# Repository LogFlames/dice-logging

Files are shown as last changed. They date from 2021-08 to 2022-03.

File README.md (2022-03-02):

# Dice logging

This is the repo containing my project during the 2021 math camp.

The project is built using an ESP8266 and accelerometer (ADXL345).

To upload the code use the ESP8266 package for the arduino IDE. 

Add this to `File > Preferences > Additional Board Manager URLs` (http://arduino.esp8266.com/stable/package_esp8266com_index.json]. Goto `Tools > Board > Board Manager` and install the ESP8266 module. Select `Generic ESP8266 Module` in `Tools > Board`.

Goto `Sketch > Include Library > Manage Libraries` and install the NTPClient. Install the Adafruit ADXL_345 library aswell.

The ClockifyAPI documentation can be found at: (https://clockify.me/developers-api)[!https://clockify.me/developers-api]

## Model
The model can be built using openSCAD. It was sliced with the PrusaSlicer at 0.15mm layer height.

If you wish to only have one model, change the following code in 'dice_cad.scad':
```cpp
for (i = [0:1]) {
    upper = i;
    translate([(-rad -2) * sign(i - 0.5), 0, 0]) {
    translate([0,0,0]) {
        union() {
------------- CODE -------------
        }
    }
    }
}
```

To this:
```cpp
for (i = [0:0]) { // Or 'for (i = [1:1]) {' to get the other half.
    upper = i;
    //translate([(-rad -2) * sign(i - 0.5), 0, 0]) {
    translate([0,0,0]) {
        union() {
------------- CODE -------------
        }
    //}
    }
}
```

## Code
In the file './dice-logger/api_code.h' you must fill in your details.

```cpp
String api_code = "<API CODE>";

std::vector<String> workspace_names;
std::vector<String> workspace_ids;

void setup_workspaces() {
    workspace_names.push_back("<WORKSPACE NAME 1>");
    workspace_ids.push_back("<WORKSPACE ID 1>");

    workspace_names.push_back("<WORKSPACE NAME 2>");
    workspace_ids.push_back("<WORKSPACE ID 2>");
}
```

If something isn't working you probably want to enable DEBUGMODE where it sends a lot of prints over Serial. Set the variable to true and upload the new code.
The `project_GET_page_size` defines how many projects it will request at once.
The `last_sides_length` defines for how many updates the die will have to be in the same position before it updates. It updates about 8 times per second, making this value divided by 8 the number of seconds of the same rotation required.
```cpp
#define last_sides_length 8
#define project_GET_page_size 12
#define DEBUGMODE false
```

The source-code also needs to contain a list of all wifi access-points it can connect to. These can be added with the line:
```cpp
wifiMulti.addAP("SSID", "password");
```

You will also every so often need to update the fingerprint of api.clockify.me, just access it with a browser and copy the SHA1 hash to the code, and recompile.

## Blikning behaviour and usage
Builtin LED:  
* (On): Probably means it is sending data to/receiving data from clockify.  
* (4hz): If the builtin LED blinks with 4hz it means it is checking what side is up.  
* (many hz <- You know when you see it): It is about to turn off (useful to know when the turn-off button has been registered)  

To save time on startup the dice will not automatically load all projects, only the ones that have been saved to one of the sides. This has been done due to most of the dice-use will not consist of configuration where this data is necessary. If you wish to configure one of the sides, press the 'Load Projects' button, it will take some time but the page will reload and the projects will be available for configuration in the dropdown.  

Another important thing to know is that if the dice only has sides configured to turn it off, it will not turn off. This is so that the user will not get locked out of configuring - if the dice automatically and instantly turns off when started.  

## Connections
I will maybe add a proper schematic here later, for now I will just write it down to document it. <- This has now become permanent, although a little bit nicer formated that before.

### Between the accelerometer and ESP8266
```
Accel: GND -> ESP8266: GND  
Accel: VCC -> ESP8266: 5V  
Accel: SCL -> ESP8266: D1  
Accel: SDA -> ESP8266: D2  
```

### Between the ESP8266 and the turn-off button
```
ESP8266: 3.3V ->  
  Button (side 1) ->  
    Button (side 2) ->  
      ESP8266: D5 ->  
        100KOhm ->  
          ESP8266: GND  
```

By: Elias Lundell

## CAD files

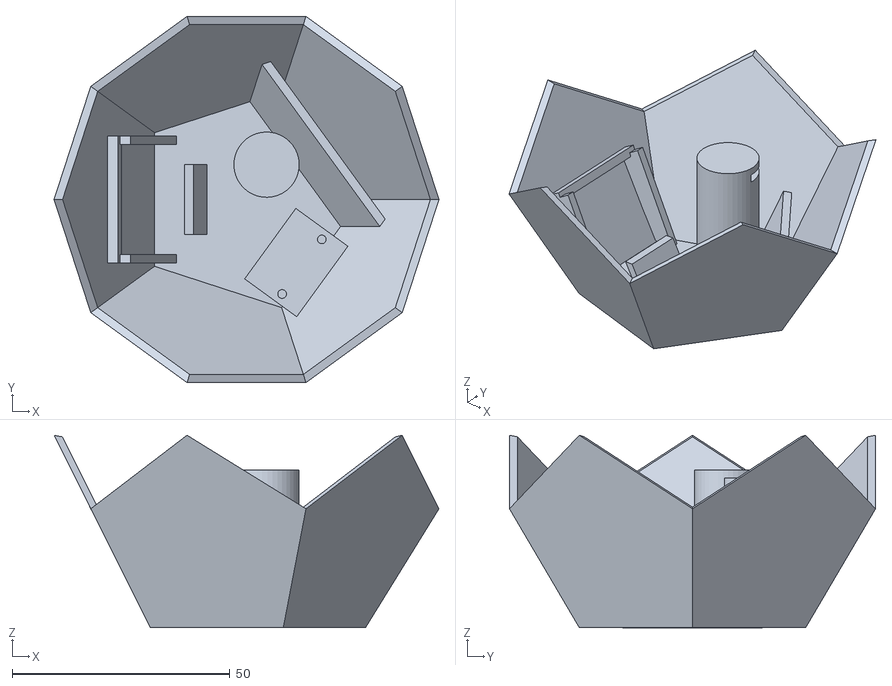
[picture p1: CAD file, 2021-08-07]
stl_files/dice_str_45_one_w_accel_battery_main_magnet.stl
88.4 x 84.1 x 44.2

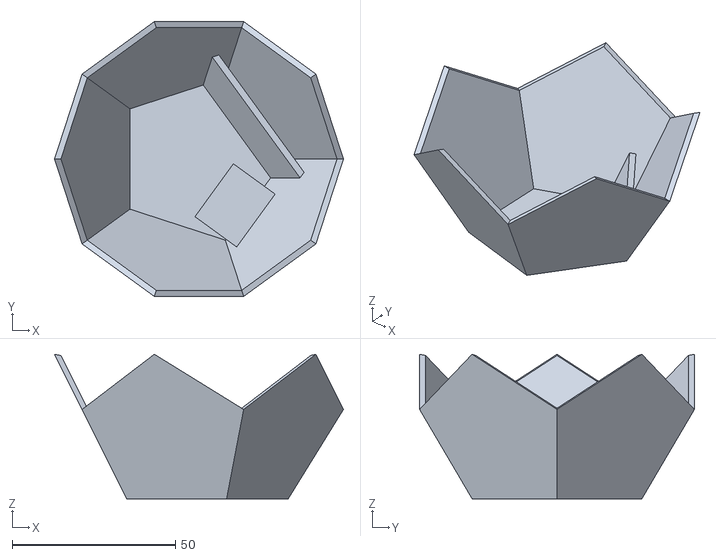
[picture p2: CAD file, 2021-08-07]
stl_files/dice_stl_45_one_full.stl
88.4 x 84.1 x 44.2

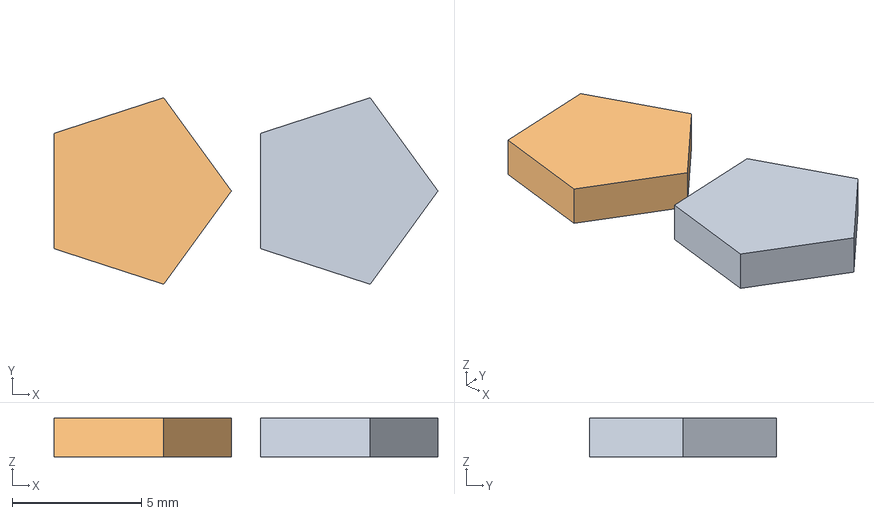
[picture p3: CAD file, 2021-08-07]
Dice.FCStd
14.9 x 7.23 x 1.50 mm

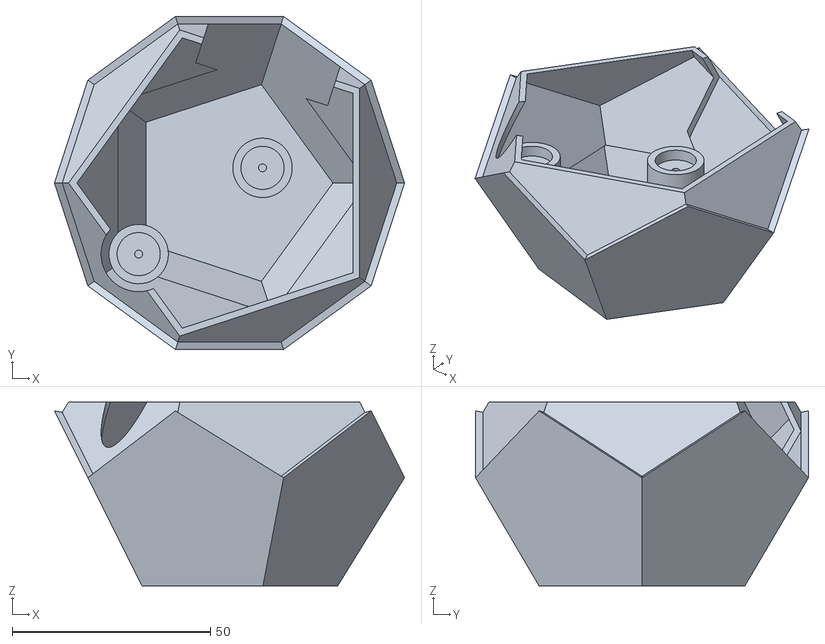
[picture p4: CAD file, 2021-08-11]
stl_files/dice_stl_v18.stl
88.4 x 84.1 x 46.4

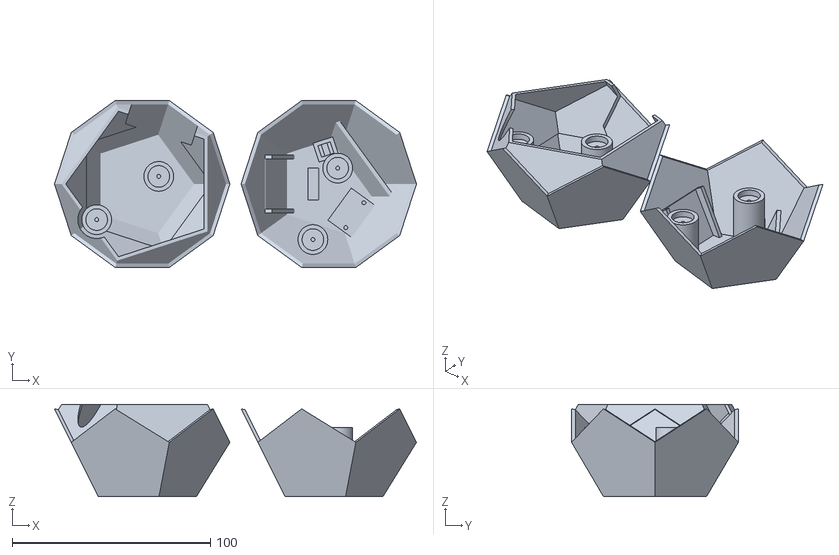
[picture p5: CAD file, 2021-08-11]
stl_files/dice_str_19_two.stl
182.4 x 84.1 x 46.4

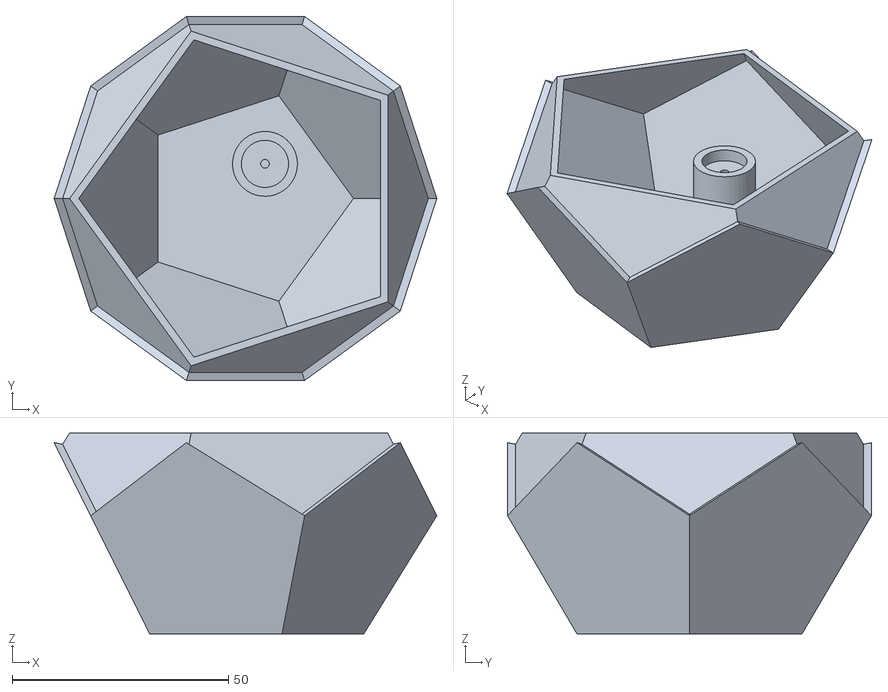
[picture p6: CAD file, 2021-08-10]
stl_files/dice_stl_one_upper_v12.stl
88.4 x 84.1 x 46.4

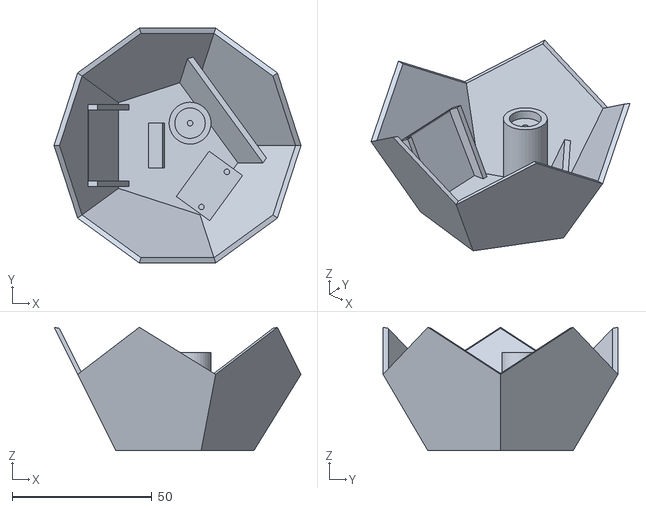
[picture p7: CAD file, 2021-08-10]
stl_files/dice_stl_45_one_raised_magnet_pillar_v11.stl
88.4 x 84.1 x 44.2

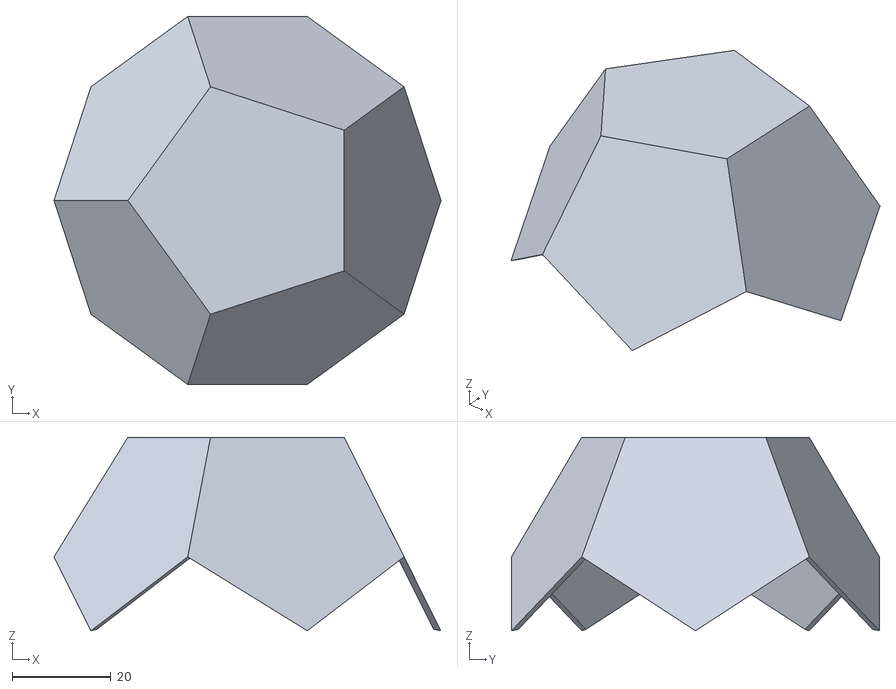
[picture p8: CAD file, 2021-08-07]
stl_files/dice_stl_40_empty.stl
78.6 x 74.7 x 39.3

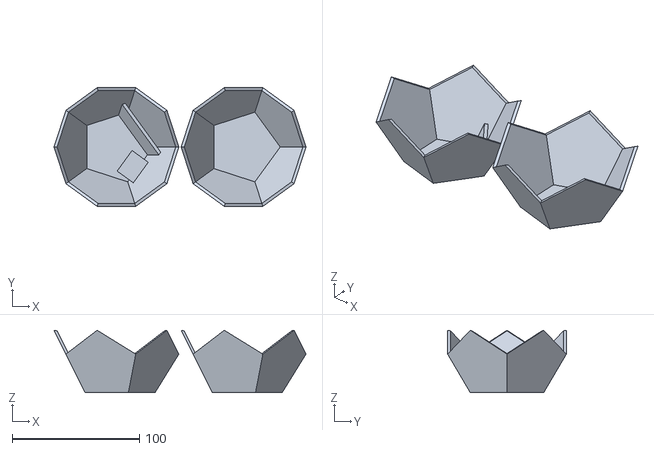
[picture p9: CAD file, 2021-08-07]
stl_files/dice_stl_50_two.stl
198.2 x 93.4 x 49.1

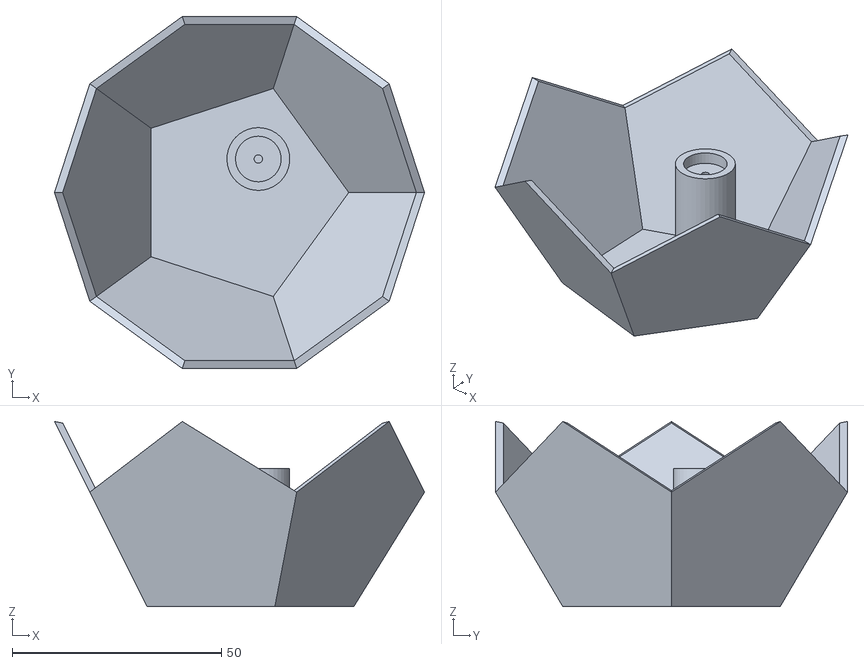
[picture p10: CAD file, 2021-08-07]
stl_files/dice_str_45_one_upper.stl
88.4 x 84.1 x 44.2

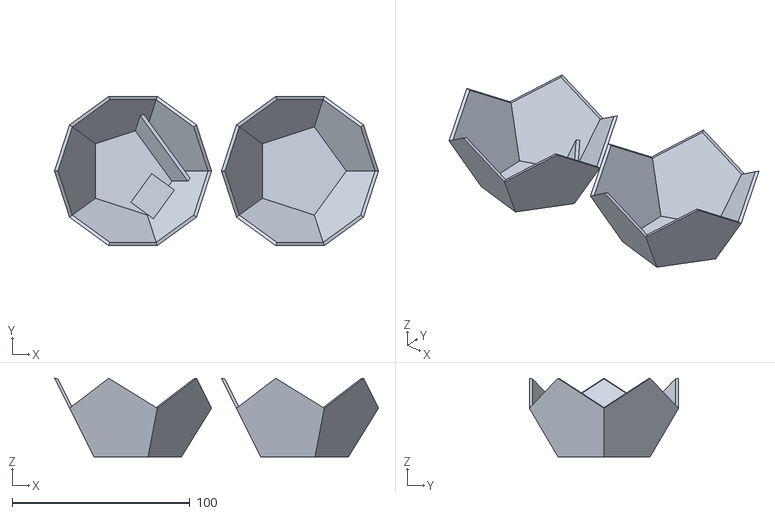
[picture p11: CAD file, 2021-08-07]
stl_files/dice_str_45_two.stl
182.4 x 84.1 x 44.2

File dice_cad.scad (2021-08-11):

$fn = 50;

upper = false;

rad = 45;
wall_thickness = 2;
battery_thickness = 5.5;
battery_height = 15;
battery_width = 35;
battery_side = 3;
accel_height = 8.5;
accel_offset = 5;
accel_depth = 15;
accel_width = 20;
accel_side = 2;
accel_pin_height = 7.5;
accel_pin_hole_distance_from_edge = 9.5;
accel_pin_top_diameter = 2;
accel_pin_bottom_diameter = 2;
main_inner_width = 16;
main_outer_width = 25.3;
main_height = 10;
main_rise = 2;
main_thickness = 5;
main_support_distance = 4;
main_support_height = 22;
main_bar_height = 24;
main_bar_width = main_outer_width + 2 * wall_thickness;
main_bar_distance = 0;//1.5;
main_side = 0;
magnet_radius = 5.2;
magnet_height = 3;
magnet_distance = 2.5;
magnet_screw_radius = 1;
magnet_screw_height = 10;
magnet_cylinder_radius = 7.5;
button_side = 6;
button_height = 3.5;
button_holder_height = 8;

r_outer = rad / sqrt(3);
r_inner = (rad - wall_thickness) / sqrt(3);
angle = 31.717474411;
angle2 = 37.3773681;
angle3 = 116.5650512;
accel_wall_dist = max(0, accel_depth - accel_height * tan( angle3 - 90));
inner_to_inner = 1.3763819 / sqrt(3) * (rad - wall_thickness);

phi = 1 / 2 + sqrt(5 / 4);

wall_p = [[-1,-1,-1] * r_outer,  
[-1,-1,1] * r_outer, 
[-1,1,-1] * r_outer, 
[-1,1,1] * r_outer, 
[1,-1,-1] * r_outer, 
[1,-1,1] * r_outer, 
[1,1,-1] * r_outer, 
[1,1,1] * r_outer,
[0,           1/phi,   phi] * r_outer, 
[0,          -1/phi,   phi] * r_outer,
[0,          1/phi,   -phi] * r_outer, 
[0,          -1/phi, -phi] * r_outer,
[1/phi,   phi,     0] * r_outer,
[-1/phi, phi,    0] * r_outer,
[1/phi,   -phi,  0] * r_outer,
[-1/phi, -phi,  0] * r_outer,
[phi,       0,      1/phi] * r_outer,
[-phi,     0,      1/phi] * r_outer,
[phi,       0,      -1/phi] * r_outer,
[-phi,     0,      -1/phi] * r_outer];

wall_p2 = [[-1,-1,-1] * r_inner,  
[-1,-1,1] * r_inner, 
[-1,1,-1] * r_inner, 
[-1,1,1] * r_inner, 
[1,-1,-1] * r_inner, 
[1,-1,1] * r_inner, 
[1,1,-1] * r_inner, 
[1,1,1] * r_inner,
[0,           1/phi,   phi] * r_inner, 
[0,          -1/phi,   phi] * r_inner,
[0,          1/phi,   -phi] * r_inner, 
[0,          -1/phi, -phi] * r_inner,
[1/phi,   phi,     0] * r_inner,
[-1/phi, phi,    0] * r_inner,
[1/phi,   -phi,  0] * r_inner,
[-1/phi, -phi,  0] * r_inner,
[phi,       0,      1/phi] * r_inner,
[-phi,     0,      1/phi] * r_inner,
[phi,       0,      -1/phi] * r_inner,
[-phi,     0,      -1/phi] * r_inner];

wall_large_p = [[-1,-1,-1] * r_outer * 100,  
[-1,-1,1] * r_outer * 100, 
[-1,1,-1] * r_outer * 100, 
[-1,1,1] * r_outer * 100, 
[1,-1,-1] * r_outer * 100, 
[1,-1,1] * r_outer * 100, 
[1,1,-1] * r_outer * 100, 
[1,1,1] * r_outer * 100,
[0,           1/phi,   phi] * r_outer * 100, 
[0,          -1/phi,   phi] * r_outer * 100,
[0,          1/phi,   -phi] * r_outer * 100, 
[0,          -1/phi, -phi] * r_outer * 100,
[1/phi,   phi,     0] * r_outer * 100,
[-1/phi, phi,    0] * r_outer * 100,
[1/phi,   -phi,  0] * r_outer * 100,
[-1/phi, -phi,  0] * r_outer * 100,
[phi,       0,      1/phi] * r_outer * 100,
[-phi,     0,      1/phi] * r_outer * 100,
[phi,       0,      -1/phi] * r_outer * 100,
[-phi,     0,      -1/phi] * r_outer * 100];

wall_large_p2 = [[-1,-1,-1] * r_outer,  
[-1,-1,1] * r_outer, 
[-1,1,-1] * r_outer, 
[-1,1,1] * r_outer, 
[1,-1,-1] * r_outer, 
[1,-1,1] * r_outer, 
[1,1,-1] * r_outer, 
[1,1,1] * r_outer,
[0,           1/phi,   phi] * r_outer, 
[0,          -1/phi,   phi] * r_outer,
[0,          1/phi,   -phi] * r_outer, 
[0,          -1/phi, -phi] * r_outer,
[1/phi,   phi,     0] * r_outer,
[-1/phi, phi,    0] * r_outer,
[1/phi,   -phi,  0] * r_outer,
[-1/phi, -phi,  0] * r_outer,
[phi,       0,      1/phi] * r_outer,
[-phi,     0,      1/phi] * r_outer,
[phi,       0,      -1/phi] * r_outer,
[-phi,     0,      -1/phi] * r_outer];

wall_f = [[8,9,1,17,3],[9,5,14,15,1],[9,8,7,16,5],[8,3,13,12,7],[3,17,19,2,13],[17,1,15,0,19]];
wall_f2 = [[3+20,17+20,1+20,9+20,8 + 20],
[1 + 20,15 + 20,14 + 20,5 + 20,9 + 20],
[5 + 20,16 + 20,7 + 20,8 + 20,9 + 20],
[7 + 20,12 + 20,13 + 20,3 + 20,8 + 20],
[13 + 20,2 + 20,19 + 20,17 + 20,3 + 20],
[19 + 20,0 + 20,15 + 20,1 + 20,17 + 20]];

wall_f3 = [[19,0,0+20,19+20],[2,19,19+20,2+20], [13,2,2+20,13+20],[12,13,13+20,12+20],[7,12,12+20,7+20],[16,7,7+20,16+20],[5,16,16+20,5+20],[14,5,5+20,14+20],[15,14,14+20,15+20],[0,15,15+20,0+20]];

battery_p = [
    [-cos(angle) * r_inner + battery_thickness,sin(angle2) * r_inner + battery_thickness * tan(20), 0],
    [-cos(angle) * r_inner + battery_thickness,-sin(angle2) * r_inner - battery_thickness * tan(20), 0],
    [-cos(angle) * r_inner + battery_thickness + wall_thickness,sin(angle2) * r_inner + (battery_thickness + wall_thickness) * tan(20), 0],
    [-cos(angle) * r_inner + battery_thickness + wall_thickness,-sin(angle2) * r_inner - (battery_thickness + wall_thickness) * tan(20), 0],
    [-cos(angle) * r_inner + battery_thickness - battery_height * tan(angle3 - 90),sin(angle2) * r_inner + battery_thickness * tan(18) + battery_height * tan(angle3  - 90 - 1), battery_height],
    [-cos(angle) * r_inner + battery_thickness - battery_height * tan(angle3 - 90),-sin(angle2) * r_inner - battery_thickness * tan(18) - battery_height * tan(angle3  - 90 - 1), battery_height],
    [-cos(angle) * r_inner + battery_thickness + wall_thickness - battery_height * tan(angle3 - 90),sin(angle2) * r_inner + (battery_thickness + wall_thickness) * tan(18) + battery_height * tan(angle3  - 90 - 1), battery_height],
    [-cos(angle) * r_inner + battery_thickness + wall_thickness - battery_height * tan(angle3 - 90),-sin(angle2) * r_inner - (battery_thickness + wall_thickness) * tan(18) - battery_height * tan(angle3  - 90 - 1), battery_height]
];
battery_f = [[0,1,3,2],[5,4,6,7],[2,3,7,6],[1,0,4,5],[0,2,6,4],[3,1,5,7]];

accel_p = [
    [-cos(angle) * r_inner,-accel_width / 2 + accel_offset ,0],
    [-cos(angle) * r_inner,accel_width / 2 + accel_offset,0],
    [-cos(angle) * r_inner + accel_wall_dist,-accel_width / 2 + accel_offset ,0],
    [-cos(angle) * r_inner + accel_wall_dist,accel_width / 2 + accel_offset,0],
    [-cos(angle) * r_inner + accel_wall_dist,-accel_width / 2 + accel_offset ,accel_height],
    [-cos(angle) * r_inner + accel_wall_dist,accel_width / 2 + accel_offset,accel_height],
    [-cos(angle) * r_inner - accel_height * tan(angle3 - 90),-accel_width / 2 + accel_offset ,accel_height],
    [-cos(angle) * r_inner - accel_height * tan(angle3 - 90),accel_width / 2 + accel_offset,accel_height]];

accel_f = [[3,1,0,2],[4,5,3,2],[3,5,7,1],[0,1,7,6],[6,4,2,0],[4,6,7,5]];

accel_pin_p = [[-cos(angle) * r_inner + accel_wall_dist - accel_pin_hole_distance_from_edge,-accel_width / 2 + accel_offset + 1.25 + accel_pin_bottom_diameter / 2,accel_height - accel_pin_height],
    [-cos(angle) * r_inner + accel_wall_dist - accel_pin_hole_distance_from_edge, accel_width / 2 + accel_offset - 1.25 - accel_pin_bottom_diameter / 2,accel_height - accel_pin_height]];
    
main_p = [
    [-cos(angle) * r_inner + main_height / cos(angle),main_inner_width / 2,0],
    [-cos(angle) * r_inner + main_height / cos(angle),-main_inner_width / 2,0],
    [-cos(angle) * r_inner + main_height / cos(angle) + main_thickness,main_inner_width / 2,0],
    [-cos(angle) * r_inner + main_height / cos(angle) + main_thickness,-main_inner_width / 2,0],
    [-cos(angle) * r_inner + main_height / cos(angle) - sin(angle) * main_rise,main_inner_width / 2,main_rise],
    [-cos(angle) * r_inner + main_height / cos(angle) - sin(angle) * main_rise,-main_inner_width / 2,main_rise],
    [-cos(angle) * r_inner + main_height / cos(angle) + main_thickness - sin(angle) * main_rise,main_inner_width / 2,main_rise],
    [-cos(angle) * r_inner + main_height / cos(angle) + main_thickness - sin(angle) * main_rise,-main_inner_width / 2,main_rise]];

main_f = [[0,1,3,2], [1,5,7,3], [0,2,6,4], [5,1,0,4], [2,3,7,6], [4,6,7,5]];

main_p2 = [
    [-cos(angle) * r_inner,main_outer_width / 2,0],
    [-cos(angle) * r_inner,main_outer_width / 2 + wall_thickness,0],
    [-cos(angle) * r_inner + main_support_distance,main_outer_width / 2,0],
    [-cos(angle) * r_inner + main_support_distance,main_outer_width / 2 + wall_thickness,0],
    [-cos(angle) * r_inner - sin(angle) * main_support_height,main_outer_width / 2,main_support_height],
    [-cos(angle) * r_inner - sin(angle) * main_support_height,main_outer_width / 2 + wall_thickness,main_support_height],
    [-cos(angle) * r_inner + main_support_distance - sin(angle) * main_support_height,main_outer_width / 2,main_support_height + tan(angle) * main_support_distance],
    [-cos(angle) * r_inner + main_support_distance - sin(angle) * main_support_height,main_outer_width / 2 + wall_thickness,main_support_height + tan(angle) * main_support_distance]];
    
main_f2 = [[1,0,2,3],[0,1,5,4],[5,1,3,7],[2,0,4,6],[6,7,3,2],[4,5,7,6]];
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

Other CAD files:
stl_files/dice_stl_two_v13.stl
stl_files/dice_stl_one_v15.stl
stl_files/dice_str_45_one_adjusted_v9.stl
stl_files/dice_stl_v16.stl
stl_files/dice_stl_one_v14.stl
stl_files/dice_stl_v17.stl
stl_files/dice_str_45_one_adjusted_v7.stl
stl_files/dice_str_45_one_adjusted_v6.stl
stl_files/dice_str_45_one_adjusted_v8.stl

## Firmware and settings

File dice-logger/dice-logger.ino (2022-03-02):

#include <time.h>
#include <fstream>
#include <LittleFS.h>
#include <NTPClient.h>
#include <WiFiUdp.h>
#include <WiFiClient.h>
#include <WiFiClientSecure.h>
#include <ESP8266WiFi.h> 
#include <ESP8266WiFiMulti.h> 
#include <ESP8266mDNS.h>
#include <ESP8266WebServer.h>
#include <ESP8266HTTPClient.h>

#include "api_code.h" // Containing the variables api_code and workspace id
#include "sensor.h"

#define wifi_max_try  10
#define duration_deep_sleep 1
#define last_sides_length 8
#define project_GET_page_size 12
#define DEBUGMODE false

// This should be built into the CORE I would assume, but it does not seem to be... Or something is not imported correctly
#define D5 14

ESP8266WiFiMulti wifiMulti;
ESP8266WebServer server(80);

void handle_root();
void handle_save();
void handle_format();
void handle_remove();
void handle_not_found();
void redirect_back_to_root();

sensors_event_t event;

std::vector<float> sides_Xs = {};
std::vector<float> sides_Ys = {};
std::vector<float> sides_Zs = {};
std::vector<String> sides_project_names = {};
std::vector<String> sides_project_ids = {};
std::vector<int> sides_workspace_indexes = {};

std::vector<String> project_names = {};
std::vector<String> project_ids = {};
std::vector<int> project_workspace_indexes = {};
String user_id = "";

const char* configuration_filename = "/configuration.txt";

WiFiUDP ntpUDP;
NTPClient timeClient(ntpUDP, "pool.ntp.org");
const char* clockify_host = "api.clockify.me";
const int httpsPort = 443;

const char* fingerprint PROGMEM = "9E 25 6F 17 C2 C5 38 8E 80 EA D2 BB AC AD 46 94 12 88 89 23";

int current_side;
int last_side;
int last_sides_index = 0;
int last_sides[last_sides_length];

bool status_led = false;

void connect_to_wifi() {
    if (DEBUGMODE) {
        Serial.print("Connecting");
    }
    int count_try = 0;
    while (wifiMulti.run() != WL_CONNECTED && WiFi.status() != WL_CONNECTED) {
        digitalWrite(LED_BUILTIN, LOW);
        delay(250);
        digitalWrite(LED_BUILTIN, HIGH);
        delay(250);
        digitalWrite(LED_BUILTIN, LOW);
        delay(250);
        digitalWrite(LED_BUILTIN, HIGH);
        Serial.print(".");
        count_try++;
        if (count_try >= wifi_max_try) {
            if (DEBUGMODE) {
                Serial.println("\n");
                Serial.println("Impossible to establish WiFi connexion, sleep a little !");
            }
            turn_off();
            return;
        }
    }

    digitalWrite(LED_BUILTIN, LOW);
    if (DEBUGMODE) {
        Serial.println("");
    }

    timeClient.begin();
    timeClient.setTimeOffset(0); // We want UTC time
}

String get_current_time() {
    time_t epoch = (time_t)timeClient.getEpochTime();
    struct tm* p_tm = gmtime(&epoch);

    int monthDay = p_tm->tm_mday;
    int currentMonth = p_tm->tm_mon+1;
    int currentYear = p_tm->tm_year+1900;
    int hour = p_tm->tm_hour;
    int min = p_tm->tm_min;
    int sec = p_tm->tm_sec;

    String currentDate = String(currentYear) + "-";
    if (currentMonth < 10) {
        currentDate += "0";
    }
    currentDate += String(currentMonth) + "-";
    if (monthDay < 10) {
        currentDate += "0";
    }
    currentDate += String(monthDay) + "T";
    if (hour < 10) {
        currentDate += "0";
    }
    currentDate += String(hour) + ":";
    if (min < 10) {
        currentDate += "0";
    }
    currentDate += String(min) + ":";
    if (sec < 10) {
        currentDate += "0";
    }
    currentDate += String(sec) + ".000Z";

    return currentDate;
}

void GET_user() {
    WiFiClientSecure client;
    client.setFingerprint(fingerprint);
    client.setTimeout(15000);

    if (!client.connect(clockify_host, httpsPort)) {
        if (DEBUGMODE) {
            Serial.print("Connection failure: "); Serial.print(clockify_host); Serial.print(":"); Serial.println(httpsPort);
        }
        return;
    }

    String url = "/api/v1/user";
    if (DEBUGMODE) {
        Serial.print("Requesting URL: "); Serial.print(clockify_host); Serial.println(url);
    }
    client.print(String("GET ") + url + " HTTP/1.1\r\n" + "Host: " + clockify_host  + "\r\n" + "X-Api-Key: " + api_code + "\r\n" + "Connection: close\r\n\r\n");
    unsigned long timeout = millis();

    while (client.available() == 0) {
        if (millis() - timeout > 5000) {
            Serial.println("Client timeout!");
            client.stop();
            return;
        }
        delay(100);
    }


    user_id = "";
    bool found_id = false;
    while(client.available() && !found_id) {
        String line = client.readStringUntil('\n'); 
        for (unsigned int i = 5; i < line.length(); i++) {
            if (line[i - 5] == '\"' &&
                line[i - 4] == 'i' &&
                line[i - 3] == 'd' &&
                line[i - 2] == '\"' &&
                line[i - 1] == ':' &&
                line[i    ] == '\"') {
                    i++;
                    while (line[i] != '\"' && i < line.length()) {
                        user_id.concat(line[i]);
                        i++;
                    }
                    found_id = true;
                    break;
            }
        }
    }
}

void GET_projects() {
    WiFiClientSecure client;
    client.setFingerprint(fingerprint);
    client.setTimeout(15000);

    project_names = {};
    project_ids = {};
    project_workspace_indexes = {};
    String line;

    for (int ws_ind = 0; ws_ind < workspace_ids.size(); ws_ind++) {
        bool found_data = true;
        int page = 1;

        while (found_data) {
            found_data = false;
            if (!client.connect(clockify_host, httpsPort)) {
                if (DEBUGMODE) {
                    Serial.print("Connection failure: "); Serial.print(clockify_host); Serial.print(":"); Serial.println(httpsPort);
                }
                return;
            }

            String url = "/api/v1/workspaces/" + workspace_ids[ws_ind] + "/projects?archived=false&page-size=" + String(project_GET_page_size) + "&page=" + String(page);
            if (DEBUGMODE) {
                Serial.print("Requesting URL: "); Serial.print(clockify_host); Serial.println(url);
            }
            client.print(String("GET ") + url + " HTTP/1.1\r\n" + "Host: " + clockify_host  + "\r\n" + "X-Api-Key: " + api_code + "\r\n" + "Connection: close\r\n\r\n");
            unsigned long timeout = millis();

            while (client.available() == 0) {
                if (millis() - timeout > 5000) {
                    Serial.println("Client timeout!");
                    client.stop();
                    return;
                }
                delay(100);
            }


            int projects_this_page = 0;
            while(client.available() && projects_this_page < project_GET_page_size) {
                line = client.readStringUntil(']');

                if (line.length() == 0) {
                    if (DEBUGMODE) {
                        Serial.println("Parsed all data from clockify");
                    }
                    break;
                }

                unsigned int i = 5;

                while (i < line.length()) {

                    if (line[i - 5] == '\"' &&
                        line[i - 4] == 'i' &&
                        line[i - 3] == 'd' &&
                        line[i - 2] == '\"' &&
                        line[i - 1] == ':' &&
                        line[i    ] == '\"') {
                            String id = "";
                            String name = "";
                            i++;
                            while (line[i] != '\"' && i < line.length()) {
                                id += line[i];
                                i++;
                            }

                            if (i + 9 >= line.length()) {
                                break;
                            }

                            i += 9;

                            if (line[i - 8] == ',' &&
                                line[i - 7] == '\"' &&
                                line[i - 6] == 'n' &&
                                line[i - 5] == 'a' &&
                                line[i - 4] == 'm' &&
                                line[i - 3] == 'e' &&
                                line[i - 2] == '\"' &&
                                line[i - 1] == ':' &&
                                line[i    ] == '\"') {
                                    i++;
                                    while(line[i] != '\"' && i < line.length()) {
                                        name += line[i];
                                        i++;
                                    }
                            }

                            if (i == line.length()) {
                                break;
                            }

                            if (DEBUGMODE) {
                                Serial.print("Id: "); Serial.print(id);
                                Serial.print(" Name: "); Serial.print(name);
                                Serial.print(" Workspace ID: "); Serial.print(workspace_ids[ws_ind]);
                                Serial.print(" Workspace Name: "); Serial.println(workspace_names[ws_ind]);
                            }
                            project_names.push_back(name);
                            project_ids.push_back(id);
                            project_workspace_indexes.push_back(ws_ind);
                            projects_this_page++;
                            if (projects_this_page >= project_GET_page_size) {
                                found_data = true;
                            }
                    }

                    i++;
                }
            }

            page++;
        }
    }

    if (DEBUGMODE) {
        Serial.println("Closing connection");
    }
}

void PATCH_project_stop() {
    WiFiClientSecure client;

    client.setFingerprint(fingerprint);
    client.setTimeout(15000);

    if (!client.connect(clockify_host, httpsPort)) {
        if (DEBUGMODE) {
            Serial.print("Connection failure: "); Serial.print(clockify_host); Serial.print(":"); Serial.println(httpsPort);
        }
        return;
    }

    for (unsigned int i = 0; i < workspace_ids.size(); i++) {
        String url = "/api/v1/workspaces/" + workspace_ids[i] + "/user/" + user_id + "/time-entries";
        if (DEBUGMODE) {
            Serial.print("Requesting URL: "); Serial.print(clockify_host); Serial.println(url);
        }
        String postData = "{\"end\":\"" + get_current_time() + "\"}";
        HTTPClient http;
        http.begin(client, String("https://") + clockify_host + url);
        http.addHeader("Content-type", "application/json");
        http.addHeader("X-Api-Key", api_code);
        int httpCode = http.PATCH(postData);
        if (DEBUGMODE) {
            String payload = http.getString();
            Serial.println(httpCode);
            Serial.println(payload);
        }

        http.end();
    }
}

void POST_project_start() {
    if (current_side < 0) {
        return;
    }

    WiFiClientSecure client;

    client.setFingerprint(fingerprint);
    client.setTimeout(15000);

    if (!client.connect(clockify_host, httpsPort)) {
        if (DEBUGMODE) {
            Serial.print("Connection failure: "); Serial.print(clockify_host); Serial.print(":"); Serial.println(httpsPort);
        }
        return;
    }

    String url = "/api/v1/workspaces/" + workspace_ids[sides_workspace_indexes[current_side]] + "/time-entries";
    if (DEBUGMODE) {
        Serial.print("Requesting URL: "); Serial.print(clockify_host); Serial.println(url);
    }
    String postData = "{\"start\":\"" + get_current_time() + "\",\"projectId\":\"" + sides_project_ids[current_side] + "\"}";
    HTTPClient http;
    http.begin(client, String("https://") + clockify_host + url);
    http.addHeader("Content-type", "application/json");
    http.addHeader("X-Api-Key", api_code);
    int httpCode = http.POST(postData);
    if (DEBUGMODE) {
        String payload = http.getString();
        Serial.println(httpCode);
        Serial.println(payload);
    }

    http.end();
}

void POST_project() {
    if (current_side == -1 || sides_project_ids[current_side].length() <= 10 || sides_workspace_indexes[current_side] == -1) { // NOTE: We should be able to compare it to "noproj". But for some reason the length is 7, probably some \r or other character at the end or begining :(
        bool only_turn_off = true;
        for (int i = 0; i < sides_project_ids.size(); i++) {
            if (sides_project_ids[i][0] != 't') {
                only_turn_off = false;
                break;
            }
        }
        if (sides_project_ids[current_side][0] == 't' && !only_turn_off) { // turn_off, otherwise just stop_projects && only work if there are other sides than 'turnoff' <- impossible to configure otherwise
            turn_off();
        } else {
            PATCH_project_stop();
        }
    } else {
        POST_project_start();
    }
}
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
void loop(void)
{
    status_led = !status_led;
    digitalWrite(LED_BUILTIN, status_led);

    if (WiFi.status() != WL_CONNECTED) {
        if (DEBUGMODE) {
            Serial.println("Lost wifi connection");
        }
        connect_to_wifi();
        return;
    }

    if (digitalRead(D5) == HIGH) {
        if (DEBUGMODE) {
            Serial.println("Turned off by user");
        }
        turn_off();
        return;
    }

    timeClient.update();

    server.handleClient();
    accel.getEvent(&event);

    int side = read_side();
    last_sides[last_sides_index] = side;
    last_sides_index = (last_sides_index + 1) % last_sides_length;

    bool all_same = true;
    int value = -2;
    for (unsigned int i = 0; i < last_sides_length; i++) {
        if (value == -2) {
            value = last_sides[i];
        }

        if (last_sides[i] != value) {
            all_same = false;
            break;
        }
    }

    if (all_same && value >= 0) {
        current_side = side;
    }

    if (current_side != last_side) {
        if (DEBUGMODE) {
            Serial.print("Changing side to: "); Serial.println(current_side);
        }
        last_side = current_side;
        POST_project();
    }

    // if (DEBUGMODE) {
        // Serial.print("Current date: "); Serial.println(get_current_time());
        // Serial.print("X: "); Serial.print(event.acceleration.x); Serial.print(" ");
        // Serial.print("Y: "); Serial.print(event.acceleration.y); Serial.print(" ");
        // Serial.print("Z: "); Serial.print(event.acceleration.z); Serial.print(" "); Serial.println("m/s^2 ");
        // Serial.print("Side: "); Serial.println(read_side()); 
    // }

    delay(128);
}

void handle_root() {
    String current_sides = "";
    for (unsigned int i = 0; i < sides_Xs.size(); i++) {
        current_sides.concat("<tr><td>");
        current_sides.concat(i);
        current_sides.concat("</td><td>");
        current_sides.concat(workspace_names[sides_workspace_indexes[i]]);
        current_sides.concat("</td><td>");
        current_sides.concat(sides_project_names[i]);
        current_sides.concat("</td><td>");
        current_sides.concat(workspace_ids[sides_workspace_indexes[i]]);
        current_sides.concat("</td><td>");
        current_sides.concat(sides_project_ids[i]);
        current_sides.concat("</td><td>");
        current_sides.concat(sides_Xs[i]);
        current_sides.concat("</td><td>");
        current_sides.concat(sides_Ys[i]);
        current_sides.concat("</td><td>");
        current_sides.concat(sides_Zs[i]);
        current_sides.concat("</td></tr>");
    }

    String current_reading = "<tr><td>";
    current_reading.concat(read_side());
    current_reading.concat("</td><td>");
    current_reading.concat(event.acceleration.x);
    current_reading.concat("</td><td>");
    current_reading.concat(event.acceleration.y);
    current_reading.concat("</td><td>");
    current_reading.concat(event.acceleration.z);
    current_reading.concat("</td></tr>");

    String project_dropdown = "";
    for (unsigned int i = 0; i < project_names.size(); i++) {
        project_dropdown +=
            "<option value=\"" +
            String(project_workspace_indexes[i]) +
            ":" +
            project_ids[i] +
            "\">" +
            workspace_names[project_workspace_indexes[i]] +
            ": " +
            project_names[i] +
            "</option>";
    }

    String html =
"<html>"
  "<head>"
    "<meta charset=\"UTF-8\"/>"
    "<style>"
      "select {"
          "margin: 8px 4px;"
          "padding: 12px 20px;"
          "border: 0px;"
          "border-radius: 8px;"
          "background-color: white;"
      "}"
      "input {"
          "padding: 12px 20px;"
          "margin: 8px 4px;"
          "box-sizing: border-box;"
          "border: 1px solid #F8F8F8;"
          "border-radius: 8px;"
          "background-color: white;"
      "}"
      "input[type=\"submit\"]:hover {"
          "transform: scale(1.12);"
      "}"
      "form {"
          "background-color: #F2F2F2;"
          "padding: 20px 20px;"
          "border-radius: 0px;"
      "}"
      "body {"
          "background-color: #white;"
      "}"
      "table {"
          "border-collapse: collapse;"
      "}"
      "th, td {"
          "border: 1px solid #DDDDDD;"
          "padding: 8px;"
      "}"
      "tr:nth-child(even){background-color: #F2F2F2;}"
      "tr:hover {background-color: #ddd;}"
      "th {"
          "padding-top: 12px;"
          "padding-bottom: 12px;"
          "text-align: left;"
          "background-color: #AEE3F6;"
          "color: white;"
      "}"
    "</style>"
    "<title>Time Logging Dice</title>"
  "</head>"
  "<body>"
    "<center>"
      "<h1>Time Logging Dice Interface</h1>"
    "</center>"
    "<h2>Configured sides</h2>"
    "<table>"
     "<tr>"
       "<th>Index</th>"
       "<th>Workspace Name</th>"
       "<th>Project Name</th>"
       "<th>Workspace ID</th>"
       "<th>Project ID</th>"
       "<th>X</th>"
       "<th>Y</th>"
       "<th>Z</th>"
     "</tr>";
    html.concat(current_sides);
    html.concat(
    "</table>"
    "<h2>Current reading</h2>"
    "<table>"
      "<tr>"
        "<th>Side</th>"
        "<th>X</th>"
        "<th>Y</th>"
        "<th>Z</th>"
      "</tr>");
    html.concat(current_reading);
    html.concat(
    "</table>"
    "<h2>Configuration options</h2>"
    "<form action=\"/getprojects\" method=\"POST\" onsubmit=\"document.getElementById('getprojects').disabled = true;\">"
      "<input type=\"submit\" id=\"getprojects\" value=\"Load Projects\" style=\"background-color: #AEE3F6\"><br>"
    "</form>"
    "<form action=\"/save\" method=\"POST\">"
      "<label for=\"project\">Choose what project to log time on<br></label>"
      "<select name=\"project\" id=\"project\">"
        "<option value=\"noproj:noproj\">No Project/Stop Logging</option>"
        "<option value=\"turnoff:turnoff\">Stop Logging and Turn Off</option>");
    html.concat(project_dropdown);
    html.concat(
      "</select><br>"
      "<input type=\"submit\" value=\"Save\" style=\"background-color: #91F28F\"><br>"
    "</form>"
    "<form action=\"/format\" method=\"POST\">"
      "<input type=\"submit\" value=\"Clear saved sides\" style=\"background-color: #FC8A8A\"><br>"
    "</form>"
    "<form action=\"/remove\" method=\"POST\">"
      "<input type=\"number\" name=\"index\" placeholder=\"Index\" required><br>"
      "<input type=\"submit\" value=\"Remove\" style=\"background-color: #FC8A8A\"><br>"
    "</form>"
  "</body>"
"</html>");

    if (DEBUGMODE) {
        Serial.println(html);
    }

    server.send(200, "text/html", html);
}

void handle_get_projects() {
    GET_projects();
    redirect_back_to_root();
}

void handle_save() {
    if (!server.hasArg("project") || server.arg("project") == NULL) {
        server.send(400, "text/plain", "400: Invalid request");
    }

    sides_Xs.push_back(event.acceleration.x);
    sides_Ys.push_back(event.acceleration.y);
    sides_Zs.push_back(event.acceleration.z);
    String project_id, ws_id;
    bool is_ws = true;
    for (unsigned int i = 0; i < server.arg("project").length(); i++) {
        if (server.arg("project")[i] == ':') {
            is_ws = false;
            continue;
        }

        if (is_ws) {
            ws_id.concat(server.arg("project")[i]);
        } else {
            project_id.concat(server.arg("project")[i]);
        }
    }

    sides_project_ids.push_back(project_id);

    if (project_id == "noproj") {
        sides_project_names.push_back("No Project/Stop Logging");
    } else if (project_id == "turnoff") {
        sides_project_names.push_back("Stop Logging and Turn Off");
    } else {
        for (unsigned int i = 0; i < project_ids.size(); i++) {
            if (DEBUGMODE) {
                Serial.println(project_ids[i]);
                Serial.println(server.arg("project"));
            }
            if (project_ids[i] == project_id) {
                sides_project_names.push_back(project_names[i]);
                break;
            }
        }
    }

    if (ws_id == "noproj") {
        sides_workspace_indexes.push_back(-1);
    } else if (ws_id == "turnoff") {
        sides_workspace_indexes.push_back(-1);
    } else {
        sides_workspace_indexes.push_back(ws_id.toInt());
    }

    write_configuration();

    redirect_back_to_root();
}

void handle_format() {
    format_memory();
    sides_Xs = {};
    sides_Ys = {};
    sides_Zs = {};
    sides_project_ids = {};
    sides_project_names = {};
    sides_workspace_indexes = {};

    redirect_back_to_root();
}
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

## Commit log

2021-08-05 Model and code files created
    [dice_cad.scad]
2021-08-07 Show current sensor reading
2021-08-08 Updated cad code
    [dice_cad.scad]
2021-08-10 Finish code
    [dice_cad.scad, dice_stl_45_one_raised_magnet_pillar_v11.stl, dice_stl_one_upper_v12.stl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]
2021-08-11 Updated readme and moved stl files
    [backup_cad.scad, dice_cad.scad, dice_stl_40_empty.stl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]
2022-02-28 Vadå fel antal brackets
2022-03-01 Update fingerprint of api.clockify.me and fix error with wrong index
    [dice-logger.ino]
